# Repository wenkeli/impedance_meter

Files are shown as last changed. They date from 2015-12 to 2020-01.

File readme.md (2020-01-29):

Electronics to measure the resistance of multi-channel animal electrodes

This project uses the Analog Devices AD5934 impedance measurement chip with the STM32 micro-controller to measure 32 channel tetrode channel assemblies, and the ability to pass up to 5uA of current through a 2 MOhm electrode, useful for lesioning the tissue surrounding the electrodes.

The firmware folder contains the STM32 MCU code for controlling the AD5934 chip and defines the user interface on the touch screen.

The hardware folder contains the schematics and PCB designs of the electronics.

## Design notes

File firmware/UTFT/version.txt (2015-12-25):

Version:
	1.0	12 Feb 2012  -  initial release
	1.1	09 Apr 2012  -	added support for more display modules
				added support for String objects to print()
				fixed a bug in printNumF()
				added optional minimum length and filler character to pintNumI() and printNumF()
				added option to disable unneeded controller chip code to minimize memory use
	1.2	14 Apr 2012  -	added support for more display modules
				added getDisplayXSize() and getDisplayYSize()
	1.3	03 Jun 2012  -	added support for more display modules
				fixed a bug in the ITDB02-25H init
	2.0	21 Jan 2013  -	added support for Arduino Due and Arduino Leonardo
				added support for the "AquaLEDSource All in One Super Screw Shield" on chipKit Max32
				added support for more display modules
				fixed a bug in printNumF()
				optimized drawLine()
				optimized 16bit data transfer
				optimized some 8bit data transfer
				added option to use pre-defined RGB565 values with setColor(), setBackColor() and fillScr()
				added functions getColor(), getBackColor(), getFont(), getFontXsize() and getFontYsize()
				added 16 VGA standard colors as pre-defined color literal
				rearranged the manual to keep related functions grouped together
	2.01	05 Feb 2013  -  fixed a bug that only shows up on linux-based systems
	2.1	29 Mar 2013  -  added support for Electronics Lees 3.2" display shield Rev B on Arduinos
				fixed a bug that only shows up on some linux-based systems
				added built-in support for using display shields designed for Arduino Uno on Arduino Mega
				changed license to CC BY-NC-SA 3.0
	2.2	01 May 2013  -  added support for ElecFreaks TFT01-5.0 and TFT01-7.0
				added support for chipKit uC32
				restructured files slightly
	2.3	08 May 2013  -  added support for transparent text background
				fixed a bug in printNumF()
	2.4	11 May 2013  -  added basic support for multiple display modules from Coldtears
	2.41	12 May 2013  -  made some changes to facilitate the use of add-on libraries
	2.42	17 Jun 2013  -  fixed a small bug in drawBitmap()
				fixed a bug in the 16-bit Arduino Due driver
	2.5	25 Jul 2013  -  fixed a bug where some lines were 1 pixel too short
				fixed a bug in the init code for 7" modules that were only visible in portrait mode
				added basic support for more display modules from Coldtears
				updated ImageConverter565 to v2.0
				added ImgConv v1.0 - Command line image converter
				added manual for image converters
				fixed some omissions in memorysaver.h
	2.51	02 Aug 2013  -  updated ImageConverter565 to v2.1
				fixed a typo in the tools manual name
	2.6	07 Sep 2013  -  added support for 4 more ElecFreaks display modules
				added support for Watterott electronics MI0283QT-9A display module
				fixed a bug in the "Arduino (ARM)/UTFT_Demo_480x272" example
	2.7	03 Nov 2013  -  added support Bobuino (ATmega1284P) 
				optimized Arduino Due driver slightly
	2.71	06 Dec 2013  -  added support for ElecFreaks TFT01-4.3
				added support for Coldtears 3.5" and 4.0" modules
				minor changes to the library constructor
				removed unused variables
	2.72	12 Dec 2013  -  added support for ElecFreaks TFT-2.4 v1.2
	2.73	16 Feb 2014  -  added support for Teensy 3.x Boards
				added support for three display modules from ElecHouse
				minor bugfixes
				added three new functions for CPLD-based displays
	2.74	20 Feb 2014  -  fixed a bug in the serial driver
	2.75	28 Mar 2014  -  added support for Coldtears 5" and 7" CPLD modules
	2.76	04 May 2014  -  added support for several display modules from DisplayModule

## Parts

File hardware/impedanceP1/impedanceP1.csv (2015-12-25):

ref | value | footprint | digikey | Field2 | Field3 | Field4 | Field5 | Field6 | Field7 | Field8
AD1 | AD5933 | ssop-16 | AD5934YRSZ-ND
AD2 | AD8605 | SOT23-5 | AD8605ARTZREEL7CT-ND
BU0 | BU4053BC | ssop-16 | BU4053BCFV-E2CT-ND
BU1 | BU4051BC | ssop-16 | BU4051BCFV-E2CT-ND
BU2 | BU4052BC | ssop-16 | BU4052BCFV-E2CT-ND
C1 | 1uF | 0402 | 445-4978-1-ND
C2 | 1uF | 0402 | 445-4978-1-ND
C3 | 1uF | 0402 | 445-4978-1-ND
C4 | 1uF | 0402 | 445-4978-1-ND
C5 | 1uF | 0402 | 445-4978-1-ND
C6 | 1uF | 0402 | 445-4978-1-ND
C7 | 1uF | 0402 | 445-4978-1-ND
C8 | 0.05uF | 0402 | 490-5413-1-ND
C9 | 47nF | 0805 | 399-8092-1-ND
C10 | 1uF | 0402 | 445-4978-1-ND
EIB1 | OMNETICS_EIB36 | OMNETICS_A79025 | A79025
EXT1 | CONN_1
EXTGND1 | CONN_1
J1 | RJ45 | RJ45_8 | 609-1046-ND
J2 | RJ45 | RJ45_8 | 609-1046-ND
OSC1 | ECS3961/3 | ECS3963/1 | XC1894CT-ND
R1 | 1.3K | 0402 | 311-1.27KLRCT-ND
R2 | 130K | 0402 | 311-127KLRCT-ND
R3 | 1.3M | 0402 | 541-1.30MLCT-ND
R4 | 13K | 0402 | P12.7KLCT-ND
R5 | 3.6K | 0402 | P3.65KLCT-ND
R6 | 365K | 0402 | 541-365KLCT-ND
R7 | 1.5M | 0402 | 541-1.50MLCT-ND
R8 | 36K | 0402 | P36.5KLCT-ND
R9 | 50K | 0402 | P49.9KLCT-ND
R10 | 50K | 0402 | P49.9KLCT-ND
U1 | CD4067 | SSOP24 | 296-32905-5-ND
U2 | CD4067 | SSOP24 | 296-32905-5-ND
U3 | AD5280 | SSOP14 | AD5280BRUZ200-ND
U4 | LM234 | TO92 | LM234Z-6/NOPB-ND

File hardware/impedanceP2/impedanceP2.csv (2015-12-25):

ref | value | footprint | Field1 | Field2 | Field3 | Field4 | Field5 | Field6 | Field7 | Field8
C1 | 4.7uF | SM0603 | 587-2786-1-ND
C2 | 4.7uF | SM0603 | 587-2786-1-ND
C3 | 10uF | SM0603 | 587-3238-1-ND
C4 | 4.7uF | SM0603 | 587-2786-1-ND
C5 | 4.7uF | SM0603 | 587-2786-1-ND
C6 | 100uF | SM1210 | 587-3152-1-ND
C7 | 300pF | SM0603 | 1276-2261-1-ND
C8 | 100uF | SM1210 | 587-3152-1-ND
C9 | 100uF | SM1210 | 587-3152-1-ND
C10 | 4.7uF | SM0603 | 587-2786-1-ND
C11 | 10uF | SM0603 | 587-3238-1-ND
C13 | 4.7uF | SM0603 | 587-2786-1-ND
D1 | LED | 0603 | 160-1447-1-ND
D3 | B220A | SMA | B220A-FDICT-ND
FI1 | ELK-E333FA | ~ | P13159CT-ND
J1 | RJ45 | RJ45-8 | 609-1046-ND
J2 | RJ45 | RJ45-8 | 609-1046-ND
J3 | USB |  | 670-1190-1-ND
L1 | 4.7uH | ~ | 308-2050-1-ND
L3 | 33uH | ~ | 445-1983-1-ND
L4 | 33uH | ~ | 445-1983-1-ND
MCP1 | MCP73831 | SOT23-5 | MCP73831T-2ATI/OTCT-ND
P1 | JST-PH2 | jst-ph-JST-PH2 | 455-1719-ND
P2 | CONN_24X2
P3 | CONN_24X2
Q1 | DMG2307L-7 | SOT-23 | DMG2307L-7DICT-ND
Q2 | DMG2307L-7 | SOT-23 | DMG2307L-7DICT-ND
R1 | 300 | SM0603 | 1276-4599-1-ND
R2 | 2K | SM0603 | 311-2.00KHRCT-ND
R3 | 100K | SM0603 | 311-100KHRCT-ND
R4 | 47K | SM0603 | 311-47.0KHRCT-ND
R5 | 47K | SM0603 | 311-47.0KHRCT-ND
R6 | 0.42 | SM0805 | P.43BHCT-ND
R7 | 180 | SM0805 | P180ADCT-ND
R8 | 10K | SM0603 | 311-10.0KHRCT-ND
R9 | 71.5K | SM0603 | 311-71.5KHRCT-ND
R10 | 47K | SM0603 | 311-47.0KHRCT-ND
R11 | 47K | SM0603 | 311-47.0KHRCT-ND
R12 | 95.3K | SM0603 | P95.3KHCT-ND
R13 | 95.3K | SM0603 | P95.3KHCT-ND
R14 | 95.3K | SM0603 | P95.3KHCT-ND
R15 | 95.3K | SM0603 | P95.3KHCT-ND
R16 | 95.3K | SM0603 | P95.3KHCT-ND
R17 | 95.3K | SM0603 | P95.3KHCT-ND
R18 | 95.3K | SM0603 | P95.3KHCT-ND
R19 | 95.3K | SM0603 | P95.3KHCT-ND
R20 | 47K | SM0603 | 311-47.0KHRCT-ND
R21 | 47K | SM0603 | 311-47.0KHRCT-ND
R22 | 47K | SM0603 | 311-47.0KHRCT-ND
R23 | 47K | SM0603 | 311-47.0KHRCT-ND
R24 | 47K | SM0603 | 311-47.0KHRCT-ND
R25 | 47K | SM0603 | 311-47.0KHRCT-ND
R26 | 95.3K | SM0603 | P95.3KHCT-ND
R27 | 95.3K | SM0603 | P95.3KHCT-ND
R28 | 4.7K | SM0603 | 311-4.70KHRCT-ND
R29 | 4.7K | SM0603 | 311-4.70KHRCT-ND
R30 | 95.3K | SM0603 | P95.3KHCT-ND
R31 | 200K | SM0603 | 311-200KHRCT-ND
R32 | 4.7K | SM0603 | 311-4.70KHRCT-ND
R33 | 4.7K | SM0603 | 311-4.70KHRCT-ND
R34 | 47K | SM0603 | 311-47.0KHRCT-ND
R35 | 100K | SM0603 | 311-100KHRCT-ND
SW1 | SWITCH_INV | ~ | EG2585-ND
U1 | MC34063 | SOIC8 | 296-17765-1-ND
U2 | ISL9111 | SOT23_6 | 296-17765-1-ND
U3 | LM324QUAD | TSSOP14 | 296-9544-1-ND
U4 | LM324QUAD | TSSOP14 | 296-9544-1-ND
U5 | LM324QUAD | TSSOP14 | 296-9544-1-ND
U6 | PCA9306 | SM8 | 296-18509-1-ND

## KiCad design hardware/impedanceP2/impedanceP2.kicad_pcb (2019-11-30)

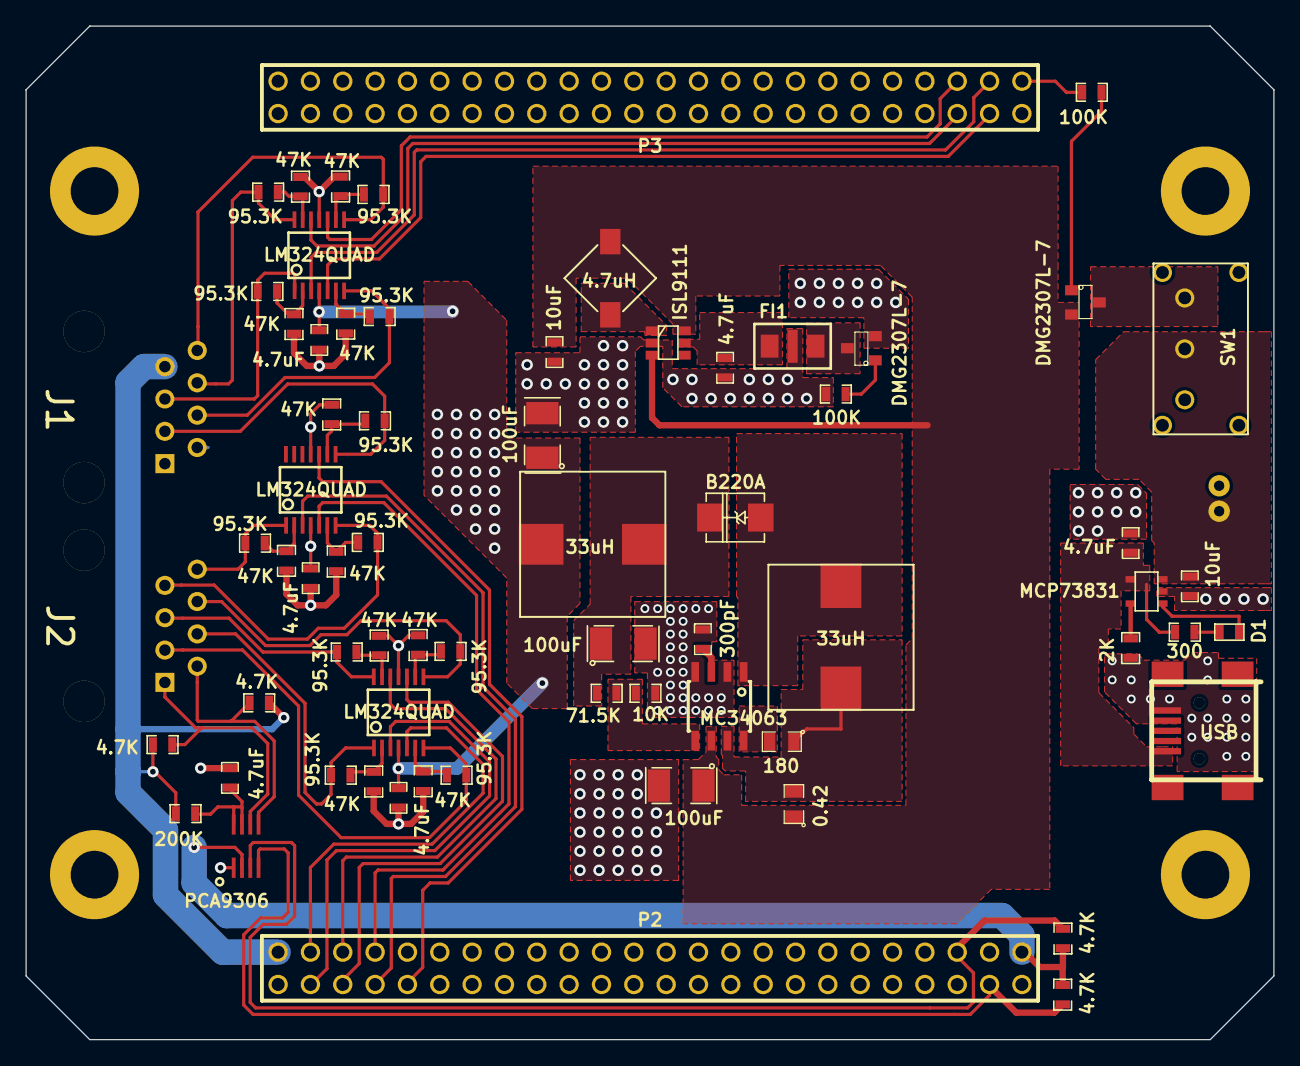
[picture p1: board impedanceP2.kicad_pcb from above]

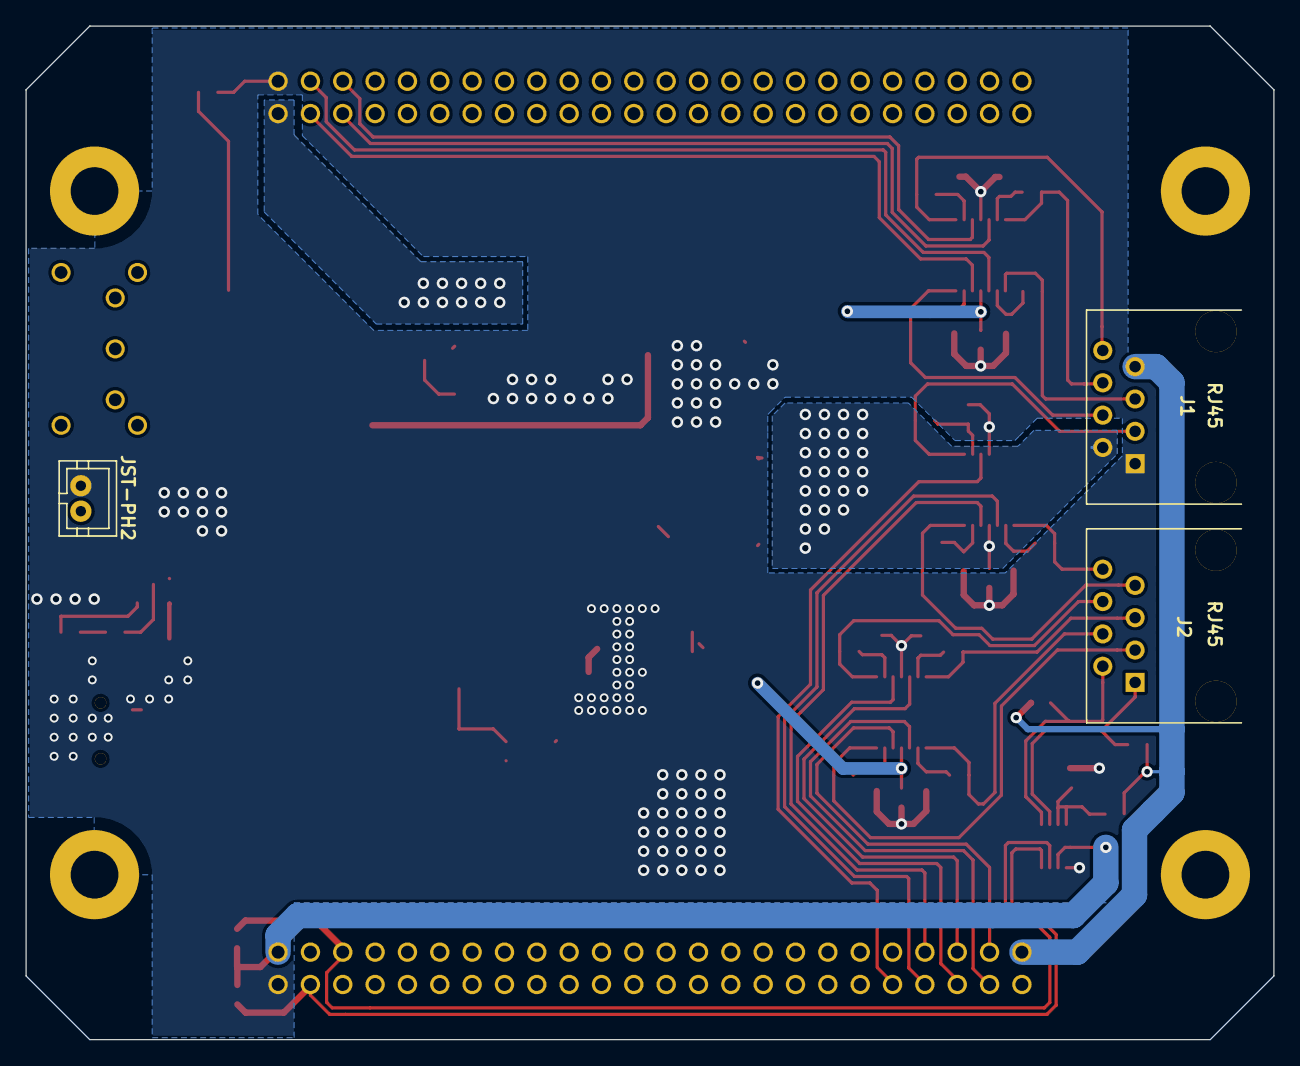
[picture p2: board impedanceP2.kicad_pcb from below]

Board: 2 copper layers, 98.0 x 79.6 mm, 73 parts (3 on the bottom side), 60 nets.

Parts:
C1, C2, C4, C5, C10, C13: 4.7uF; SM0603_Capa
C3, C11: 10uF; SM0603_Capa
C6, C8, C9: 100uF; SM1210
C7: 300pF; SM0603_Capa
D1: LED; SM0603
D3: B220A; DO-214AC(SMA)
FI1: ELK-E333FA; ELK_FILTER
J1, J2: RJ45; RJ45_8
J3: USB; USB_MINI_B
L1: 4.7uH; SMD_CDR_INDUCTOR
L3, L4: 33uH; SLF_INDUCTOR
MCP1: MCP73831; SOT23-5
P1: JST-PH2; jst-ph-JST-PH2
P2, P3: CONN_24X2; PIN_ARRAY_24X2
PIN_ARRAY_1, PIN_ARRAY_1#2, PIN_ARRAY_1#3, PIN_ARRAY_1#4: Val**; PIN_ARRAY_1
Q1, Q2: DMG2307L-7; DMG2307L
R1: 300; SM0603_Resistor
R2: 2K; SM0603_Resistor
R3, R35: 100K; SM0603_Resistor
R4, R5, R10, R11, R20, R21, R22, R23, R24, R25, R34: 47K; SM0603_Resistor
R6: 0.42; SM0805
R7: 180; SM0805
R8: 10K; SM0603_Resistor
R9: 71.5K; SM0603_Resistor
R12, R13, R14, R15, R16, R17, R18, R19, R26, R27, R30: 95.3K; SM0603_Resistor
R28, R29, R32, R33: 4.7K; SM0603_Resistor
R31: 200K; SM0603_Resistor
SW1: SWITCH_INV; EG1224
U1: MC34063; SOIC8
U2: ISL9111; SOT23_6
U3, U4, U5: LM324QUAD; TSSOP14
U6: PCA9306; SM8

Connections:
+5V: C1.1, J3.1, MCP1.4, R1.2
/3.3VOUT: P2.48, R28.1, R29.2, U6.2
/5VOUT: J1.7, P2.2, P3.2, Q2.S, R31.1, R32.1, R33.2
/10VOUT: C4.1, C9.1, C10.1, C13.2, J1.2, L4.2, U3.4, U4.4, U5.4
/INH: P2.9, U5.10
/INHV10: J1.3, R30.1, U5.8
/SCL: P2.44, R28.2, U6.3
/SCL5V: J2.1, R32.2, U6.6
/SDA: P2.45, R29.1, U6.4
/SDA5V: J2.2, R33.1, U6.5
/VBAT: C11.1, MCP1.3, P1.1, SW1.2
/VMOS: C3.2, C6.1, L1.2, Q1.S, R6.1, U1.6, U2.3, U2.6
/X2: P2.3, U4.3
/X2V10: J2.4, R14.2, U4.1
/X4A: P2.7, U5.3
/X4AV10: J2.8, R26.2, U5.1
/X4B: P2.8, U5.5
/X4BV10: J2.7, R27.2, U5.7
/X8A: P2.4, U4.5
/X8AV10: J2.3, R15.2, U4.7
/X8B: P2.5, U4.10
/X8BV10: J2.6, R19.1, U4.8
/X8C: P2.6, U4.12
/X8CV10: J2.5, R18.1, U4.14
/X16S0: P3.3, U3.3
/X16S0V10: J1.5, R12.2, U3.1
/X16S1: P3.4, U3.5
/X16S1V10: J1.4, R13.2, U3.7
/X16S2: P3.5, U3.10
/X16S2V10: J1.8, R17.1, U3.8
/X16S3: P3.6, U3.12
/X16S3V10: J1.6, R16.1, U3.14
GND: C1.2, C2.1, C3.1, C4.2, C5.2, C6.2, C7.1, C8.2, C9.2, C10.2, C11.2, C13.1, FI1.2, J1.1, J3.5, MCP1.2, P1.2, P2.47, P3.1, R2.2, R3.1, R4.1, R5.1, R8.2, R10.1, R11.1, R20.2, R21.2, R22.2, R23.2, R24.1, R25.1, R34.2, R35.1, U1.2, U1.4, U2.2, U3.11, U4.11, U5.11, U6.1
unnamed: C2.2, R31.2, U6.7, U6.8
unnamed: R5.2, R13.1, U3.6
unnamed: R4.2, R12.1, U3.2
unnamed: R16.2, R20.1, U3.13
unnamed: R17.2, R21.1, U3.9
unnamed: R8.1, R9.2, U1.5
unnamed: D3.1, L3.2, U1.1
unnamed: L3.1, R6.2, R7.1, U1.7
unnamed: R7.2, U1.8
unnamed: C7.2, U1.3
unnamed: C5.1, FI1.1, U2.5
unnamed: L1.1, U2.1
unnamed: FI1.3, Q2.D
unnamed: C8.1, D3.2, L4.1, R9.1
unnamed: R25.2, R27.1, U5.6
unnamed: R24.2, R26.1, U5.2
unnamed: R30.2, R34.1, U5.9
unnamed: Q2.G, R35.2
unnamed: R18.2, R22.1, U4.13
unnamed: R10.2, R14.1, U4.2
unnamed: R11.2, R15.1, U4.6
unnamed: R19.2, R23.1, U4.9
unnamed: D1.2, MCP1.1
unnamed: MCP1.5, R2.1
unnamed: D1.1, R1.1
unnamed: Q1.D, SW1.3
unnamed: Q1.G, R3.2

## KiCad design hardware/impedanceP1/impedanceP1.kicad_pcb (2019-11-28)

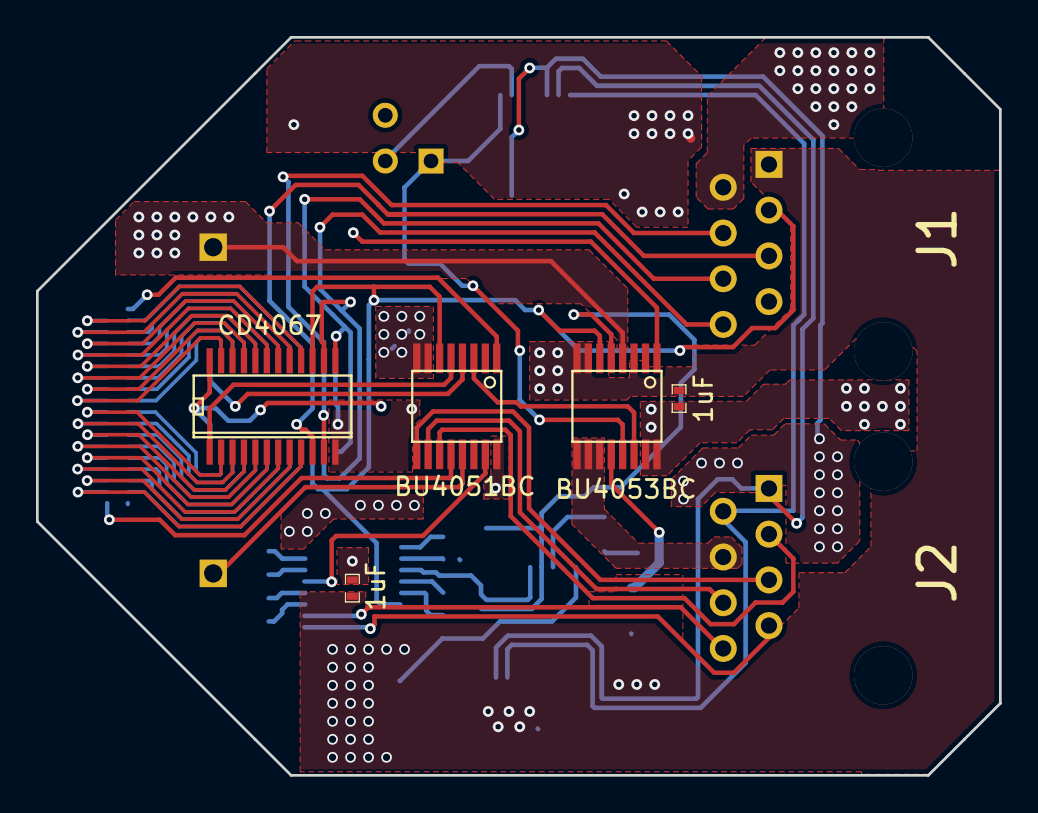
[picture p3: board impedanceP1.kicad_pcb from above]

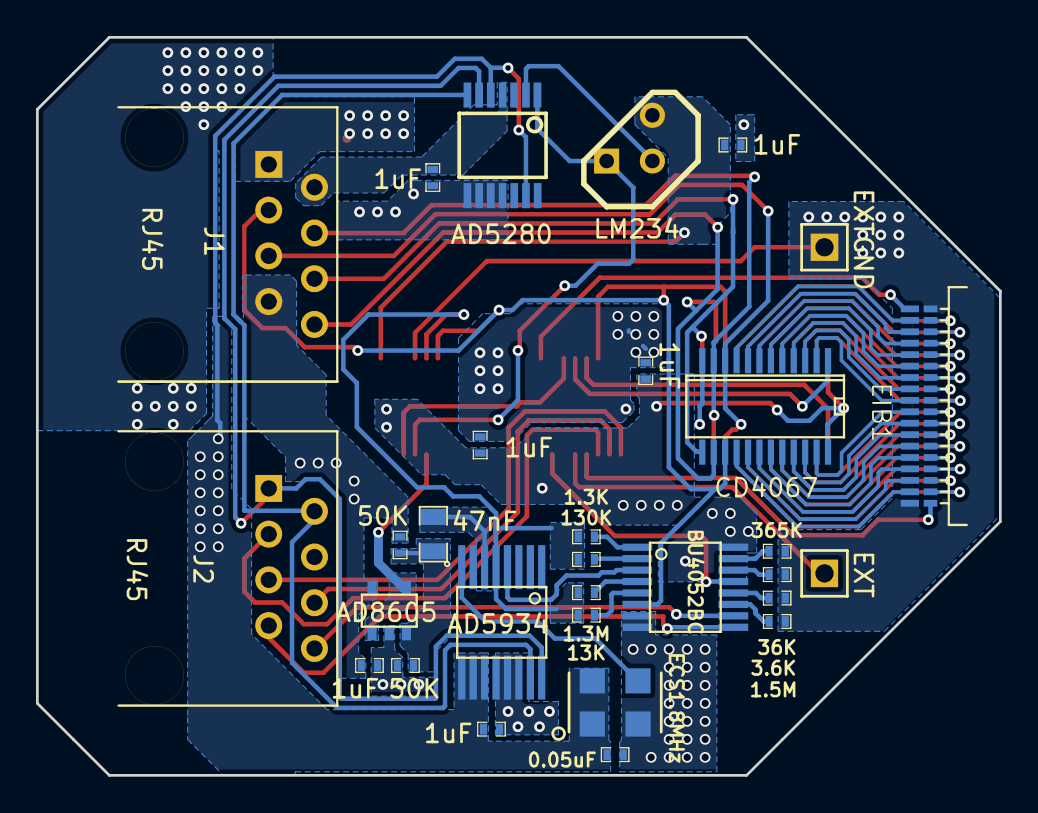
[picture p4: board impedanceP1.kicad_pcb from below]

Board: 2 copper layers, 53.5 x 41.0 mm, 35 parts (30 on the bottom side), 73 nets.

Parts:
AD1: AD5934; ssop-16
AD2: AD8605; SOT23-5
BU0: BU4053BC; ssop-16
BU1: BU4051BC; ssop-16
BU2: BU4052BC; ssop-16
C1, C2, C3, C4, C5, C6, C7, C10: 1uF; SM0402_c
C8: 0.05uF; SM0402_c
C9: 47nF; SM0805
EIB1: OMNETICS_EIB36; OMNETICS_A79025
EXT1: EXT; PIN_ARRAY_1
EXTGND1: EXTGND; PIN_ARRAY_1
J1, J2: RJ45; RJ45_8
OSC1: ECS3961_3; ECS3963_1
R1: 1.3K; SM0402_r
R2: 130K; SM0402_r
R3: 1.3M; SM0402_r
R4: 13K; SM0402_r
R5: 3.6K; SM0402_r
R6: 365K; SM0402_r
R7: 1.5M; SM0402_r
R8: 36K; SM0402_r
R9, R10: 50K; SM0402_r
U1, U2: CD4067; SSOP24
U3: AD5280; SSOP14
U4: LM234; TO92

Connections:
/5VOUT: AD1.9, AD1.10, AD1.11, AD2.5, C2.2, C8.2, C10.2, J1.7, OSC1.1, OSC1.4, R10.2, U3.5, U3.13
/10VOUT: BU0.15, BU0.16, BU1.16, BU2.16, C1.2, C3.2, C4.2, C5.2, C6.2, J1.2, U1.24, U2.24, U3.4
/B2: EIB1.20, U1.9
/B3: EIB1.21, U1.8
/B4: EIB1.22, U1.7
/B5: EIB1.23, U1.6
/B6: EIB1.24, U1.5
/B7: EIB1.25, U1.4
/B8: EIB1.26, U1.3
/B9: EIB1.27, U1.2
/B10: EIB1.28, U1.23
/B11: EIB1.29, U1.22
/B12: EIB1.30, U1.21
/B13: EIB1.31, U1.20
/B14: EIB1.32, U1.19
/B15: EIB1.33, U1.18
/B16: EIB1.34, U1.17
/B17: EIB1.35, U1.16
/CAL: BU1.15, BU2.13
/CURPROG: U3.2, U4.2
/CURPWR: BU0.1, C7.2, U4.3
/CURSRC: BU0.13, U3.1, U4.1
/EIBGND: BU0.4, EIB1.18, EIB1.36, EXTGND1.1, R5.2, R6.2, R7.2, R8.2
/EXT: BU1.13, EXT1.1
/INHV10: BU0.6, BU1.6, BU2.6, J1.3, U1.15, U2.15
/PWOUT: BU0.14, BU1.3
/REF1: BU1.1, EIB1.1
/REF2: BU1.12, EIB1.19
/RFB: AD1.4, BU2.3
/SCL5V: AD1.16, J2.1, U3.6
/SDA5V: AD1.15, J2.2, U3.7
/T2: EIB1.2, U2.9
/T3: EIB1.3, U2.8
/T4: EIB1.4, U2.7
/T5: EIB1.5, U2.6
/T6: EIB1.6, U2.5
/T7: EIB1.7, U2.4
/T8: EIB1.8, U2.3
/T9: EIB1.9, U2.2
/T10: EIB1.10, U2.23
/T11: EIB1.11, U2.22
/T12: EIB1.12, U2.21
/T13: EIB1.13, U2.20
/T14: EIB1.14, U2.19
/T15: EIB1.15, U2.18
/T16: EIB1.16, U2.17
/T17: EIB1.17, U2.16
/TESTIN: AD1.5, BU0.5, R1.1, R2.1, R3.1, R4.1
/TESTOUT: AD2.1, AD2.4, BU0.12
/TOUTAMP: AD2.3, C9.1, R9.2, R10.1
/X2V10: BU0.9, BU0.10, BU0.11, J2.4
/X4AV10: BU2.10, J2.8
/X4BV10: BU2.9, J2.7
/X8AV10: BU1.11, J2.3
/X8BV10: BU1.10, J2.6
/X8CV10: BU1.9, J2.5
/X16A: BU1.5, U1.1
/X16B: BU1.4, U2.1
/X16S0V10: J1.5, U1.10, U2.10
/X16S1V10: J1.4, U1.11, U2.11
/X16S2V10: J1.8, U1.14, U2.14
/X16S3V10: J1.6, U1.13, U2.13
GND: AD1.12, AD1.13, AD1.14, AD2.2, BU0.3, BU0.7, BU0.8, BU1.7, BU1.8, BU2.7, BU2.8, C1.1, C2.1, C3.1, C4.1, C5.1, C6.1, C7.1, C8.1, C10.1, J1.1, OSC1.2, R9.1, U1.12, U2.12, U3.8, U3.9, U3.10, U3.11
unnamed: BU2.11, R7.1
unnamed: BU2.14, R8.1
unnamed: BU2.5, R4.2
unnamed: BU2.15, R6.1
unnamed: BU2.12, R5.1
unnamed: AD1.8, OSC1.3
unnamed: AD1.6, C9.2
unnamed: BU2.2, R2.2
unnamed: BU2.1, R1.2
unnamed: BU2.4, R3.2

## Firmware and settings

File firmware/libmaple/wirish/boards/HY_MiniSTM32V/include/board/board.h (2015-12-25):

#ifndef _BOARD_HY_MINISTM32V_H_
#define _BOARD_HY_MINI_STM32V_H_

#define Port2Pin(port, bit) ((port-'A')*16+bit)

	#define CYCLES_PER_MICROSECOND  72

//#define CYCLES_PER_MICROSECOND	(F_CPU/1000000)

#define SYSTICK_RELOAD_VAL      (CYCLES_PER_MICROSECOND*1000-1)

#define BOARD_LED_PIN           Port2Pin('B', 0)
#define BOARD_LED1_PIN			Port2Pin('B', 1)
#define BOARD_BUTTON_PIN        Port2Pin('C', 13)
#define BOARD_BUTTON1_PIN		Port2Pin('B', 2)

#define BOARD_NR_USARTS         5
#define BOARD_USART1_TX_PIN     Port2Pin('A', 9)
#define BOARD_USART1_RX_PIN     Port2Pin('A',10)
#define BOARD_USART2_TX_PIN     Port2Pin('D', 5)
#define BOARD_USART2_RX_PIN     Port2Pin('D', 6)
#define BOARD_USART3_TX_PIN     Port2Pin('D', 8)
#define BOARD_USART3_RX_PIN     Port2Pin('D', 9)
#define BOARD_UART4_TX_PIN      Port2Pin('C',10)
#define BOARD_UART4_RX_PIN      Port2Pin('C',11)
#define BOARD_UART5_TX_PIN      Port2Pin('C',12)
#define BOARD_UART5_RX_PIN      Port2Pin('D', 2)

#define BOARD_NR_SPI            3
#define BOARD_SPI1_NSS_PIN      Port2Pin('A', 4)
#define BOARD_SPI1_MOSI_PIN     Port2Pin('A', 7)
#define BOARD_SPI1_MISO_PIN     Port2Pin('A', 6)
#define BOARD_SPI1_SCK_PIN      Port2Pin('A', 5)
#define BOARD_SPI2_NSS_PIN      Port2Pin('B',12)
#define BOARD_SPI2_MOSI_PIN     Port2Pin('B',15)
#define BOARD_SPI2_MISO_PIN     Port2Pin('B',14)
#define BOARD_SPI2_SCK_PIN      Port2Pin('B',13)
#define BOARD_SPI3_NSS_PIN      Port2Pin('A',15)
#define BOARD_SPI3_MOSI_PIN     Port2Pin('B', 5)
#define BOARD_SPI3_MISO_PIN     Port2Pin('B', 4)
#define BOARD_SPI3_SCK_PIN      Port2Pin('B', 3)

#define BOARD_NR_GPIO_PINS      80
#define BOARD_NR_PWM_PINS       16
#define BOARD_NR_ADC_PINS       16
#define BOARD_NR_USED_PINS      35 // ala42 not set yet
#define BOARD_JTMS_SWDIO_PIN    Port2Pin('A',13)
#define BOARD_JTCK_SWCLK_PIN    Port2Pin('A',14)
#define BOARD_JTDI_PIN          Port2Pin('A',15)
#define BOARD_JTDO_PIN          Port2Pin('B', 3)
#define BOARD_NJTRST_PIN        Port2Pin('B', 4)

#define BOARD_USB_DISC_DEV      GPIOB
#define BOARD_USB_DISC_BIT      7

#endif

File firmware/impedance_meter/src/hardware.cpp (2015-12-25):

/*
 * hardware.cpp
 *
 *  Created on: Jun 16, 2014
 *      Author: consciousness
 */

#include "../include/hardware.h"

CurrentSrc curSrc;
ImpedanceMeasure impedance(&resistorMap, &x8Map);
UTFT screen(SSD1289, 48+11, 48+5, 48+7, 48+6);
UTouch tPanel(5, 4, 7, 6, 16+6);

void initHardware()
{
	gpio_init_all();

	//initialize I2C
	i2c_init(I2C2);
	i2c_disable(I2C2);
	//clock setup must be done before enabling device
	//minimum of 2 MHz
	i2c_set_input_clk(I2C2, 2);
	//number of cycles for half period of SCL
	//set up for 10KHz
	//so far the clock seems to be stuck in 100KHz
	I2C2->regs->CCR=0x03E8;
	//i2c_set_clk_control(I2C2, 0x000003E8);
	//in standard mode, number of cycles per us+1
	i2c_set_trise(I2C2, 0x0003);
	i2c_master_enable(I2C2, 0);
	//end I2C initialization

	initChannels();

	screen.InitLCD(LANDSCAPE);

	tPanel.InitTouch(PORTRAIT);
	tPanel.setPrecision(PREC_EXTREME);


	impedance.init();
}

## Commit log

2015-12-25 initial commit for hardware schematics
    [impedanceP1.csv, impedanceP1.kicad_pcb, impedanceP1.sch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]
2015-12-26 added an empty main.cpp and made sure it’s not in the gitignore entry. this is needed for compilation to be successful in impedance_meter.
2019-11-28 updated to kicad 5 and clean up
    [impedanceP1-2019-11-28-11-56-48.sch, impedanceP1.kicad_pcb]
2019-11-30 updated to kicad 5 and cleanup
    [impedanceP2-2019-11-28-15-26-57.sch, impedanceP2.kicad_pcb]
